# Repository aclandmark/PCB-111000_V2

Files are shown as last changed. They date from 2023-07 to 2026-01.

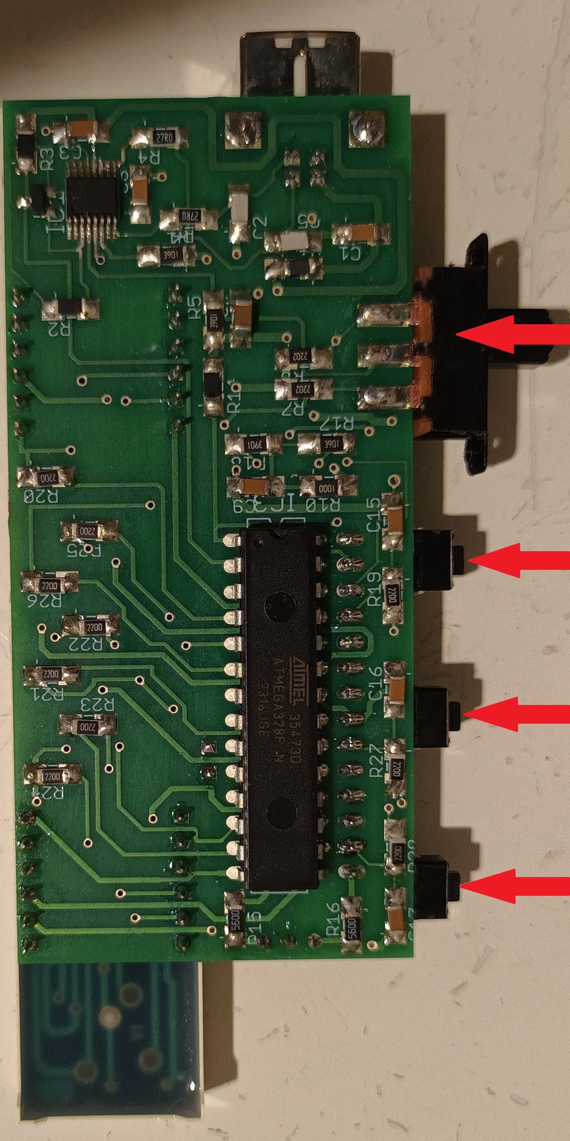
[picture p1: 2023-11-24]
Documents/PCB-111000_V2_Bottom_view.jpg

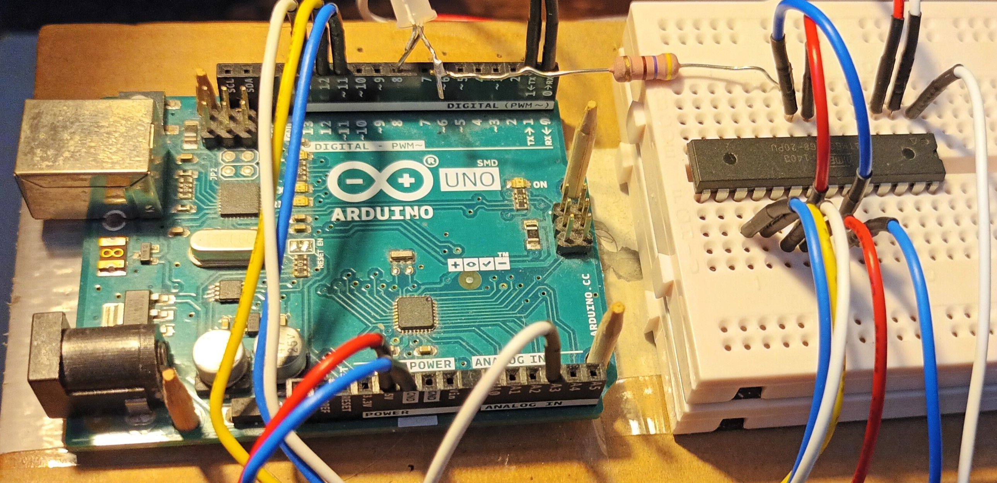
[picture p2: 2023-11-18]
Documents/UNO_programs_the_Atmega168.jpg

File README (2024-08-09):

PCB111000 has beeen developed as a learning aid for the C language when applied to AVR devices.  
It consists of a USB bridge to communicate with a PC, an 8 digit display and two AVR devices. 
One of the AVR devices (Atmega 328) hosts a programmer and miniOS which drives the display, 
the other (Atmega168), the user device, hosts user projects.

An I2C bus is used to link the two devices.
All user projects are compiled using Arduino, system projects use Arduino or Studio 7 if needed.
The boards are set up using the UNO to host a bespoke programer.  See repository "UNO_as_an_AVR_programer". 

See repository "PCB-111000/1_Documentation/1_PCB 111000 leaflet.pdf" for general information and a block diagram of the original development. 

There are three versions of PCB111000:

PCB_111000_V2 using two Atmega devices and the FTDI FT230XS USB bridge
PCB_111000_UNO_V2 A simplified plug in version for use with the UNO
PCB_111000_CP2102 Using one Atmega one ATtiny and a CP2102 module for USB connectivity.

In PCB_111000_UNO_V2 and PCB_111000_CP2102 the user device is an Atmega328 which hosts
a bootloader as well as the user projects.

In PCB_111000_CP2102 the I2C bus is replaced with a one wire firmware UART.

Originally 56 projects were developed for use with PCB111000.
These have been revised over the years and are now as follows

20 very short projects provided to show what a C program looks like and explore basic methods of program flow control
9 projects exploring the operation of the recever transmitter (USART) block
7 projects exploring interrupts
4 projects exploring bit operatons, division and the conversion between 8 bit binary and decimal numbers
11 projects based on the Arduino USART library with reset analysis including
	Interger, prime and scientific numbers
	Integer roots and a pie estimator
	Power series to compute real number powers and trig functions
	A floating point number to string sbroutine
	Displays to simulate gravity, the pendulum and a noise waveform.
9 Projects to Illustate driving the display from the keyboard and user switches, includes a simple
calculator and floating point number to 8 digit display.
7 Projects used to build simple clocks and stop watches
6 Projects used to illustrate use of Atmel Studio 7
8 projects used to illustrate the operation of floating point numbers, tested using power series as above
and the generation of pulse and sawtooth waveforms by supperimposing sine wave upon one another.
5 projects to test the operation of the PCB during assembly
5 projects used to exlore the calibration of the RC oscillators used to clock the devices.

Any bugs:	Of course there are especially in the conversion of a floating point number to 8 digits.
		Initially I tried to fix them, but stopped.  If they are of no interest to ayone else 
		then they are of no nterest to me either.

Projects for  PCB_111000_UNO_V2 and PCB_111000_CP2102:  Projects and the mini-OS for each of these pcbs 
requires updating however both include most of the initial projects.

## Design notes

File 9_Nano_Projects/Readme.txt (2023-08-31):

PCB111000_UNO and PCB111000_CP2102 projects adapted for use on original PCB111000 pcbs and compiled using Arduino Nana configured for an Atmega168 processor.

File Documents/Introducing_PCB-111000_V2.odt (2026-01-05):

PCB_111000_V2: Getting a new pcb up and running

1. Introduction

PCB_111000_V2 is a development of PCB_111000.

Both pcbs are loaded with

An Atmega 168 which hosts user projects

An Atmega 328. This hosts a mini-OS which:

Drives an 8 digit display

Hosts a pcb bootloader that programs the Atmega 168

Provides a variety of services for use by user projects

Differences are:

For the HW

The FETS used to drive the display are no longer fitted

For the SW

User projects have been revised and are now compiled using Arduino

System programs are compiled using Studio 7

PCB initialisation is carried out using the following Arduino sketches rather than bespoke HW

8_UNO_AVR_programmer_V3

5_Project_pcb_168_V2.30_Arduino_V2

2. Setting up PCB-111000_V2: Basic steps

Step 1 The PCB is loaded with all components except the displays and the Atmega devices

Step 2

Open the sketch “8_UNO_AVR_programmer_V3”. Under Tool/Board select Arduino UNO. Connect the UNO to the PC check the port number and upload the sketch.

Step 3

Close the sketch assemble the HW (see section 3) and with the aid of the Br@y++ terminal emulator use the UNO to:

Upload “5_Project_pcb_168_V2.30_Arduino_V2” to the Atmega 168

Calibrate it’s internal RC oscillator

Allow the Atmega 168 to run so that it can upload string data to its EEPROM.

Note:

Terminal emulator runs at 38.4KB and uses default settings.

See section 4 for more details.

Step 4 Load the Atmega 168 device onto the PCB111000 and test, then add the Atmega 328.

Step 5

Run “5_Project_pcb_168_V2.30_Arduino_V2” under the control of Br@y++ to setup the Atmega 328 (See section 5 for more details) by:

Uploading the mini-OS to its flash

Checking the calibration of its internal RC oscillator.

Uploading the “Hello world” strings to its EEPROM

Step 6 Overwrite “5_Project_pcb_168_V2.30_Arduino_V2” with user projects.

(See sections 6 and 7.)

Step 7 Upgrade the mini_OS if necessary (See section 8).

3. Hardware (HW) details


UNO used to program the Atmega168 before it is soldered onto the PCB111000_V2 Note: Atmega328 pin numbers given for a DIP28 device Upload “8_UNO_AVR_programmer_V3” sketch before placing the Atmega168 | UNO | | | Plug-in pcb
| UNO Pin | Atmega 328 | | Atmega168
| | Pin | Function | Pin
| 0 (Rx) | 2 | RXD | 2
| 1 (Tx) | 3 | TXD | 3
| 11 | 17 | MOSI | 17
| 12 | 18 | MISO | 18
| 13 | 19 | SCK | 19
| A3 | 26 | PC3 | 1 (Reset)
| GND | | | 8, 22
| 5V | | | 7,20
| 8 | 14 | PB0 | LED driver

4. Driving “8_UNO_AVR_programmer_V3”

Having uploaded the sketch to a UNO open Br@y++ and set it up as follows:

8 data bits, 1 stop bit, no parity or handshaking and a baud rate of 38.4KB

Click on “scan” to identify the comm port and then click on connect:

The following user prompt should be generated:

“s s s s s s s…………….”

Step 1 Click mouse pointer in the text box (at the bottom of the Br@y++ window) and

press -s- to get

“Atmega 168 detected.

Press -p- to program flash, -r- to run target, -d- to clear the target EEPROM or -x- to escape.”

Step 2 Press -p- and send “5_Project_pcb_168_V2.30_Arduino_V2.ino.eightanaloginputs”

Step 3 Follow instructions to Cal device then get user prompt “P/S P/S P/S………….”

Step 4 Press -s-, change bit rate when asked and send Text_files\on-chip_strings.txt

A bug Sometimes random text following programming. Power cycle and reprogram.

Optional steps

At P/S prompt press -v- to get program name plus version “Project_pcb_168_V2.30_Arduino”

Reset UNO and change the BR to 38.4kB to restore user prompt “s s s s s s s…………….”

Press -s- then -d- to clear “on-chip_strings” and cal bytes from Atmega168 EEPROM

Reset UNO to restore user prompt “s s s s s s s…………….”

Press -s- then -t- to recalibrate the Atmega 328 and restore user prompt “P/S P/S…...…”

Reset UNO to restore user prompt “s s s s s s s…………….”

Press -s- then -r- to restore user prompt “P/S P/S P/S………….”

Press -s- and reprogram the on-chip strings

Reset UNO to restore user prompt “s s s s s s s…………….”

Press -s- then -x- to escape

Reprogram the Atmega168 and note that it now offers a recalibration

5 Driving “5_Project_pcb_168_V2.30_Arduino_V2”

5.1 Add the Atmega 168

Solder the Atmega 168 to the PCB-111000_V2.

Press the DPDT switch left

Connect the pcb to a PC running Br@y++ running at 57.6KB.

Check the port and the user prompt “P/S P/S P/S…………..” should be generated.

Press -p- and the response TTND (Target not detected) should also be generated.

This confirms that the USB port is working correctly.

5.2 Add the Atmega 328

Solder on the Atmega 328 and press -p- again to generate the prompt:

“ATMEGA 328 detected

Press -P- to send a program file -E- to send a text file (or X to escape).

p/e p/e p/e p/e p/e p/e…..”

5.3 Upload the mini-OS to the Atmega 328

Press -p- and send

Mini-OS_V2\Hex_files\CC_files\Mini-OS_V26_CC.hex

When the LED stops flashing send 2_pcb_Bootloader_V4_28_CC.hex

Note: This assumes that Common Cathode displays are to be used. Similar files are present for Common Anode displays.

5.4 Auto cal the Atmega 328

Follow instructions to auto cal the Atmega238 and restore the “P/S……” prompt.

5.5 Upload the “Hello_world” file to the Atmega 328 EEPROM

Press -p- then -e- then -w- and send “Text_files\Hello_world.txt several times as requested.

Finally press any key to read back the file from EEPROM.

6. Run simple User Project

Press the DPDT switch right to get the “p/r p/r p/r …...” (May need to press the pcb reset switch.)

Press -p- and send

“9_Nano_Projects\System_programs\Proj_9F_Test_Proj_1\ Proj_9F_Test_Proj_1.ino.eightanaloginputs”

At the “p/r p/r p/r …...” prompt press -r- and operate the DPDT switch.

A column of numbers will be printed out.

Press sw1 to repeat.

Operate the DPDT switch and press the reset switch to restore the “p/r p/r p/r …...” prompt.

This confirms that the Atmega328 is being programmed properly and the displays can be added.

7. Check the displays

Displays are driven using a multiplexer which can make fault finding difficult.

Repeat as for section 6 but send “Proj_9G_Test_PCB_Assembly.ino.eightanaloginputs”. This turns off the multiplexer and illuminates digits one at a time.

Check for dry joints or solder bridges if any segments fail to work. This test was particularly relevant for version 1 when FETs were used to drive the display. In their absence in version 2 tracking is much simpler and solder bridges/dry joints are much less prevalent.

8. To upgrade the mini_OS

Push the DPDT switch right and press the reset switch.

Press -p- at the “p/r p/r p/r p/r p/r….” user prompt

and send 5_Project_pcb_168_V2.30_Arduino_V2.ino.eightanaloginputs

Run the project to get the “P/S P/S P/S………….”

Press S and reload file “on-chip_strings.txt” containing programmer strings

Press P then upload the new mini-OS as described in section 5.3

Note: Remember to delete line :00000001FF from end of new mini-OS file

9. Optional system files

Mini-OS_Resources\Eeprom_subroutines_PRN_alt.c:

In early designs PRN generator write to the EEPROM was too frequent and EEPROM burnout occurred. In this file the PRN uses a different location. It should be used if the

Message from the OS is always the same.

Bootloader_resources\Bootloader_main_with_OS_reset.c

This enables user projects to reset the mini-OS which is necessary if the I2C bus crashes which it does with some routines, especially I2C_Tx_2_integers().

This optional file has only been adopted for use with some boards because of the time needed for testing. See section 14 for more details.

10 Default User Project

At the p/r p/r prompt press -x- in place of -r-. This will give a series of options depending upon the project. These include a simple default project to check that the displays are being driven correctly, a print out from the “Hello World” file and details about the soft ware including the version. Note: This facility is not included with all projects but can easily be added.

11 SW downloads

There are two essential software applications that must be downloaded onto this PC. They are:

The Arduino development environment. Go to https://www.arduino.cc/en/software and download it from the Microsoft store.

Bray++ version 20130820 which can be downloaded from https://www.sites.google.com/site/terminalbpp/

Almost as important are

The portable version of Programmers notepad which can be downloaded from

http://www.pnotepad.org/download/.

An excellent text written by Joe Pardue that can be downloaded from

https://epdf.pub/c-programming-for-microcontrollers.html

The Atmega data sheet that can be downloaded from

https://www.docdroid.net/Q6jfzd3/atmega48a-pa-88a-pa-168a-pa-328-p-ds-ds40002061a-pdf

12 Getting the PCB manufacturing files

The Eagle pcb design software is required

Place the Eagle circuit design and layout drawings in a convenient folder

Open the Eagle pcb application. This takes the user to the Eagle control panel.

Click on (expand)

CAM Jobs

Examples and open example_2_layer.cam

Find and click on the Select Board button (Bottom left of the window)

Navigate to the layout drawing and select it

Its name will be confirmed at the bottom of the window

Click on

Process Job

Open folder (Eagle names this CAMOutputs)

Only the DrillFiles and GerberFiles are required for pcb fabrication

Use windows to send them to a compressed (zipped) folder.

This can be E-mailed to a pcb manufacturer.

13. PCB assembly

Eagle circuit design and layout drawings can be found under

PCB-111000_V2\PCB 111000_Eagle_drawings together with a parts list.

The Eagle pcb design software is required to view these

Photographs of the pcb are shown below.

Note the locations of the following components

The user switches sw1, sw2 and sw3

The double pole double throw switch (DPDT)

The reset switch

The Atmega 168 which is in the top side of the pcb (note also the location of pin 1)

The Atmega 328 which is in the under side of the pcb (note also the location of pin 1)

Because of the way the two Atmega devices are assembled the pins of one of them must be soldered from the device side of the board.

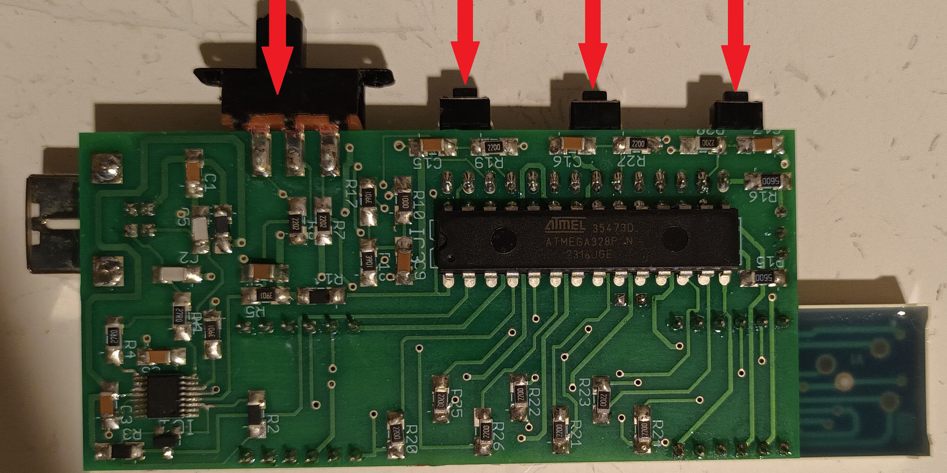
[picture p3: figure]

Note also the orientation of the two display modules.

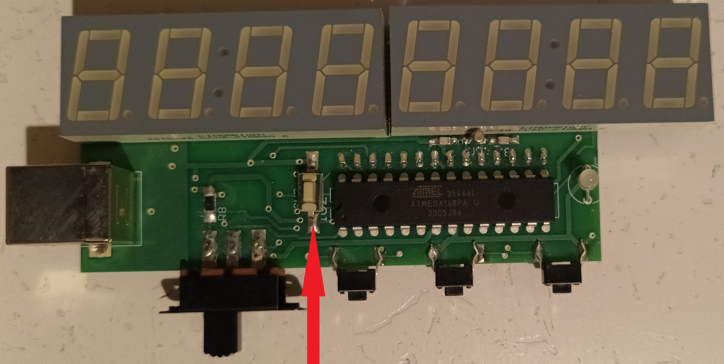
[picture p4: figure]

DPDT switch sw1 sw2 sw3 | Photo of PCB-111000V2 under side. Solder the Atmega328 to this side carefully noting its placement and the location of pin 1.
| Photo of PCB-111000V2 top side. Solder the Atmega168 to this side carefully noting its placement and the location of pin 1. Note also the orientation of the display modules
Reset switch

14 System Block diagram

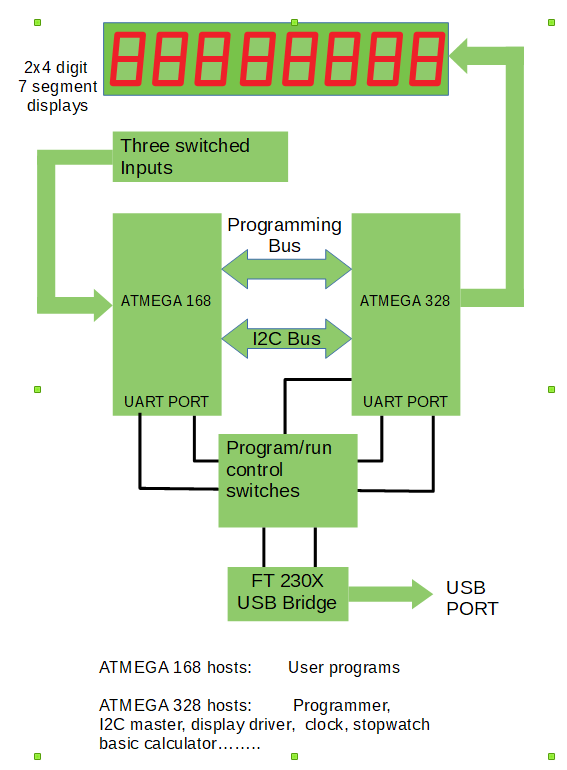
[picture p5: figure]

15 I2C bus crash

Projects designed to create patterns on the display are liable to crash if left running indefinitely or even after say 5 minutes.

A major cause of this is the I2C bus: slave and master somehow get out of step with the result that the slave finds itself waiting for a signal from the master that has already gone or for some reason never comes. The watch dog timer with interrupt is used to detect this situation. The interrupt service routine puts a reset pulse on the mini-OS IC. This alone Causes program control to jump to the programmer (location 0x7000). Therefore immediately before the reset pulse a low is put on one of the programming bus lines (PB4). The programmer detects this and sends program control to location 0x0000 (i.e. the mini-OS).

The user project “waiting_for_I2C_master” macro must be modified as follows:

activate interrupts to enable a jump to the watch dog ISR

Ensure that a time out is generated after a short (but unknown) wait as follows:

Replace the line

while (!(TWCR & (1 << TWINT)));

or

while (!(TWCR & (1 << TWINT)))wdr();

with the lines

{int m = 0; while((!(TWCR & (1 << TWINT))) && (m++ < 5000))wdr();\

if (m >= 4999){sei(); while((!(TWCR & (1 << TWINT))));}}\

These changes have only been made in projects

5I_Noise_waveform

5J_Gravity

5J_pendulum

They may easily generate unexpected side effects in other projects.

To indicate that the special version of the programmer is being used

the “p/r p/r p/r…….. user prompt in file

Bootloader_main_with_OS_reset.c

Has been changed to “p/g p/g p/g………….”

16 Programmer Bug

If -p- is pressed at the p/r prompt the first task of the programmer is to switch the target device into programming mode after which its programming memory is reset and the user is requested to send the code. Occasionally the device fails to enter programming mode however this condition has never persisted long enough to be investigated. This may be because there is a dry joint connecting the Atmega reset pins high via the 10K resistors.

In some versions of PCB111000, programming memory has only been reset after the first character of the new code has been detected. This was not found to work reliably in PCB111000_V2 so once -p- has been selected there is no escape and programming memory must be refreshed if anything is to work even the default program.

17 Mini-OS bug

The Mini-OS was originally developed using winAVR with the compiler set for full optimisation, in other words to make the executable file as small as possible.

WinAVR has subsequently been replaced by Atmel Studio 7. For this compiler full optimisation generates an executable file that is even smaller than the one generated by WinAVR. Unfortunately the mini-OS failed to function with this level of optimisation. When optimisation was turned off normal operation of the mini-OS was restored.

It is now believed that it is the I2C bus that fails with full optimisation. Ideally this should be investigated and the fault remedied so that with full optimisation and using Studio 7 everything works correctly.

This investigation has not been carried out. Instead use of the watch dog timer has been investigated. In many ways this is the more useful approach since the watch dog has widespread applications.

Recalibrating the Atmega devices

The Atmega 328 device which hosts the min-OS is recalibrated automatically.

Power cycle with DPDT to the right.

Use PCB-1111000_V2\9_Nano_projects\System_programs\ to recalibrate the Atmega 168 the user device. Note: it has not been observed that recalibration has ever been required.

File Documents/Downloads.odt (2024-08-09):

Downloads required for the Arduino Project: Checked July 2024

The Arduino development environment.

Go to https://www.microsoft.com/en-gb/store/b/sale

Click on search and type Arduino IDE

Click again, then go to download

File : Arduino IDE Installer.exe will be downloaded.

Click on it to install Arduino IDE

Note: Arduino places two folders under Documents: Arduino and Arduinodata

My current version Arduino 1.8.19 (Windows Store 1.8.57.0)

Just downloaded Arduino 1.8.19 (Windows Store 1.8.57.0)

New version Arduino 2.3.2 expected soon.

Bray++ Terminal

Go to https://www.sites.google.com/site/terminalbpp/

Several versions are available: Only one is suitable for use here.

Due to some confusion download

Terminal20130116 Last modified 16 Jan 2013 AND

Terminal20130820 Last modified 20 Aug 2013

Don’t bother with the latest version (The auto scroll does not appear to work)

I found Terminal20130116 to be OK

Programmers notepad

Go to http://www.pnotepad.org/download/ and download the portable edition

Unzip it and click on pn.exe

Text by Joe Pardue

Go to https://epdf.pub/c-programming-for-microcontrollers.html

Click on download PDF

The Microchip data sheet

Go to https://www.docdroid.net/Q6jfzd3/atmega48a-pa-88a-pa-168a-pa-328-p-ds-ds40002061a-pdf

and download.

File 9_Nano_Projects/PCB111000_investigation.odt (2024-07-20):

Development of Github_PCB-111000

Create new folders 9_Nano_Projects

and Resources_nano_projects

Go to ATMEGA_project_work_BKP_30_Sept_2022\I2C_apps_project_V10 and

Copy the files in 2_User_projects_V1_9\Resources_V12 to Resources_nano_projects

Create a new Arduino project 1_first_project

and save it under 9_Nano_Projects

Note that folder 1_first_project is created for the project

Open 2_User_projects_V1_9\….\….\Open Proj_1A1

Copy its contents into the Arduino project

Copy Proj_1A1 hex file and

Proj_1A1_header_file

into the 1_first_project folder along side the 1_first_project project

Rename the header file First_project_header

Initial tests

Upload the hex file to a PCB111000

Check it runs immediately following an -r- keypress

Gives Version data following an -x- keypress

Close and reopen the Arduino Project so that it includes the header file

Edit the #include statement to read #include "First_project_header.h"

Compile the project using Nano board Atmega 168 processor

Using setup_HW_basic;

and setup_HW

Check the following text is printed out OK

1 for OS version

2 for system data

3 Message from the OS (x to escape)

The Default project runs correctly

OS version

OS: I2C_V20_0_CA

System data:

SW information: Operating system I2C_V20_0_CA Projects V1_9 and Bootloader V4_21_CA. External programmer V2_30B

Actual operating system is Github_PCB-111000_V2\Mini-OS_V22

Update mini-OS

Github_PCB-111000 contains mini-OS version12 and 13.

Replace this OS with mini-OS_Version 20 copied from

ATMEGA_project_work_BKP_30_Sept_2022\I2C_apps_project_V10

Rebuilding mini-OS_V20 will require use of Atmel Studio 7.

Reprogramming the Atmega 328 with require the programs saved under

ATMEGA_project_work_BKP_30_Sept_2022\I2C_apps_project_V10

To update the mini-OS DO NOT EXPECT TO NEED TO DO THIS

At the p/r prompt put “4_Project_pcb_168_V2.30B” on the Atmega 168

At the ‘P’ prompt press

‘P’ to reprogram the mini-OS

‘E’ to update the “Hello world” file.

Note: Other programmers that should no longer be needed.

Version A: Same as Version B but B has one extra line to trigger auto cal of the 328.

4a_Project_pcb_328_V2.31A runs on an Atmega328

Programmer_pcb_328_V1.10 runs on a 328 and is used to put V2.30B on a 168 or replicate itself on another 328

6_BL_programmer_V1_5 was a development tool and is no longer required

If more boards are to be built a UNO will be used to put V2.30B onto an Atmega 168 and also calibrate it.

The Atmega 328 programmer applies the following config bytes to the 168

FF D5 C2 EB

V1.10 applies FF D7 E2 EB

Differences effect the brown out level and start up time.

New locations for user cal bytes Check carefully that these are always used

0x1FF User calibration byte

0x1FE User calibration byte

0x1FD Default calibration byte

0x1FC PRN generator random number HB

0x1FB PRN generator random number LB

Note: Only two locations are used here but write to EEPROM every 45 secs

2_User_projects_V1_9\Proj_9_System_projects\Proj_9A_168_manual_cal()

writes EEPROM location 0x1FA to zero.

No reason for this has been found and the line should be commented out

Problems

1 Note old problem with redefinition of

volatile char PCMSK0_mem, PCMSK2_mem;

in File I2C_subroutines_2

void I2C_Tx_float_display_control(void)

and #include "../Header_files/I_O_from switches.h"

Solution copied from PCB111000_UNO Compiles OK but not fully tested.

2 I2C_subroutines_2 line 121 SOLVED

Commented out for time being.

Calibration programs All OK

Copy the following two calibration routines to

9_Nano_Projects\System_programs

2_User_projects_V1_9\Proj_9A_168_manual_cal

and \Proj_9B_168_auto_cal

Compile with Arduino_nano_168 and calibrate two pcbs successfully.

Note Problem 2 above

Note: The Atmega 328 (mini-OS device calibrates itself automatically at every POR)

provided the DPDT is switched to the right.

1_first_project 12 examples

Example 1 Ramp with SW reset Tested OK

Example 1A Ramp with WDT generated reset Tested OK

Example 2 Back and forth with WDT Tested OK

Example 3 Chase (spurious wdr(); removed) Tested OK

Example 4 Single ellipse (spurious wdr(); removed) Tested OK

Example 5 Double ellipse (spurious wdr(); removed) Tested OK

Example 6 Upper/lower see saws Tested OK

Example 7 Moving top Tested OK

Example 7A Moving top (with reset on sw3) Tested OK

Example 8 Leds leapfrog WDT added Tested OK

Example 9 LEDS light up in random order (with reset) Tested OK

Example 10 Default program with WDT Tested OK

Tested with setup_HW_extra

Example_1 Modes 0 – 4 tested OK Saved as Example_1E

Example_4 Modes 0 – 4 tested OK Saved as Example_4E

Example_7 Modes 0 – 4 tested OK Saved as Example_7E

Example_9 Modes 0 – 4 tested OK Saved as Example_9E

2_Receiver_Transmitter_Basic

Example_1 Tested OK

Example_2 Tested OK

Example_3 Tested OK

Example_4 Reset implemented Tested OK

Example_5 Reset implemented Tested OK

Example_6 Reset implemented Tested OK

Example_7 Tested OK

Example_8 Tested OK

Example_9 Tested OK

Tested with setup_HW_extra

Example_1

Example_3

Example_5

Example_7

3_Interrupts_and_switches

Basic HW HW_Extra

3A_UART_timer_interrupts OK OK

3B_Pin_Change_Interrupt OK OK

3C_reaction_time_tester OK OK

3D_timer_PCI_interrupts OK OK

3E_Keypress_logger OK OK

3F_Prime_numbers OK OK

3G_Prime_numbers_plus OK OK

4_binary_and_bit_operations

1_Bit_ops_1 OK OK

2_Bit_ops_2 OK OK

3_Division_subroutine OK OK

4_Char_to_binary OK OK

5_Timers Performance degraded by tendency of I2C bus to crash.

Resolved using watch dog with interrupt

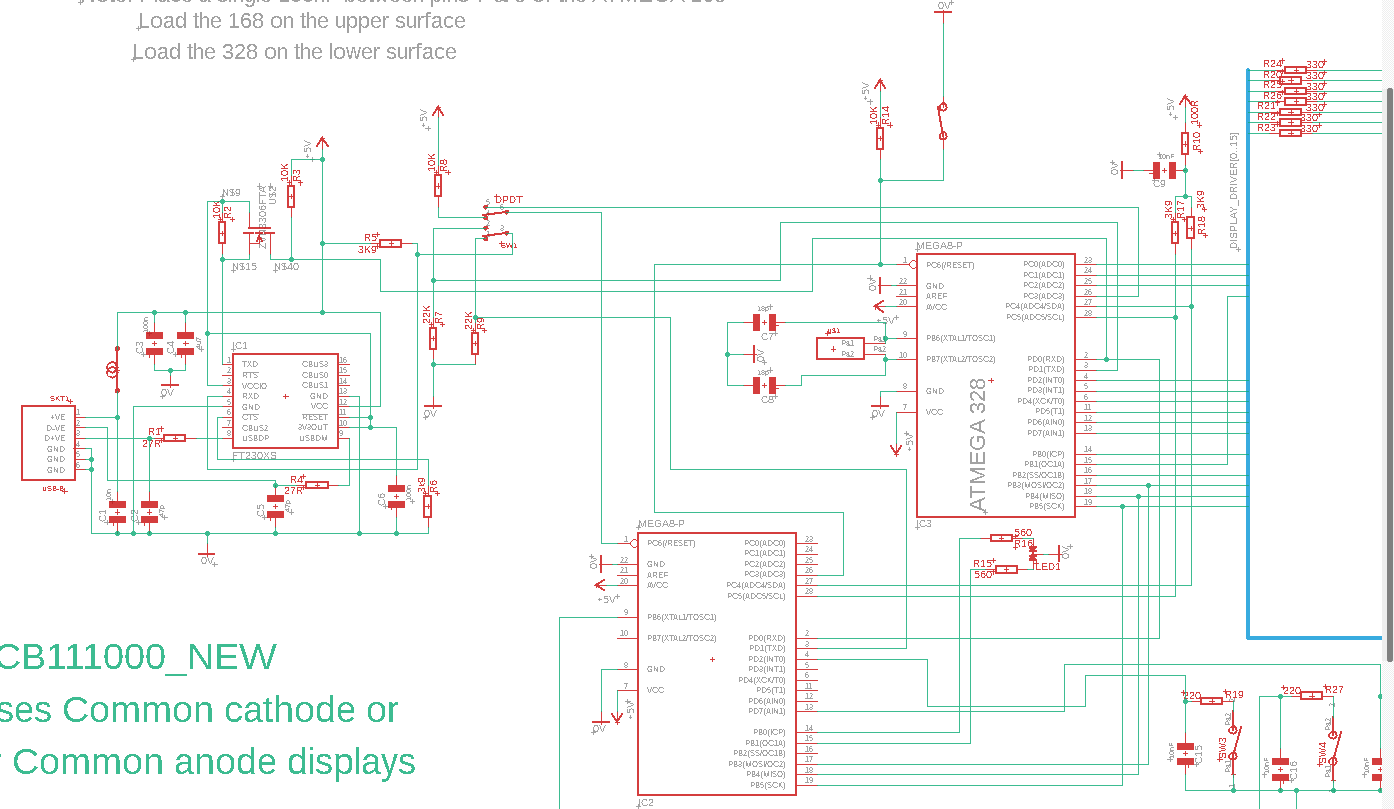
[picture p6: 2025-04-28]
PCB 111000_Eagle_drawings/Version 2 design/Schematic.bmp

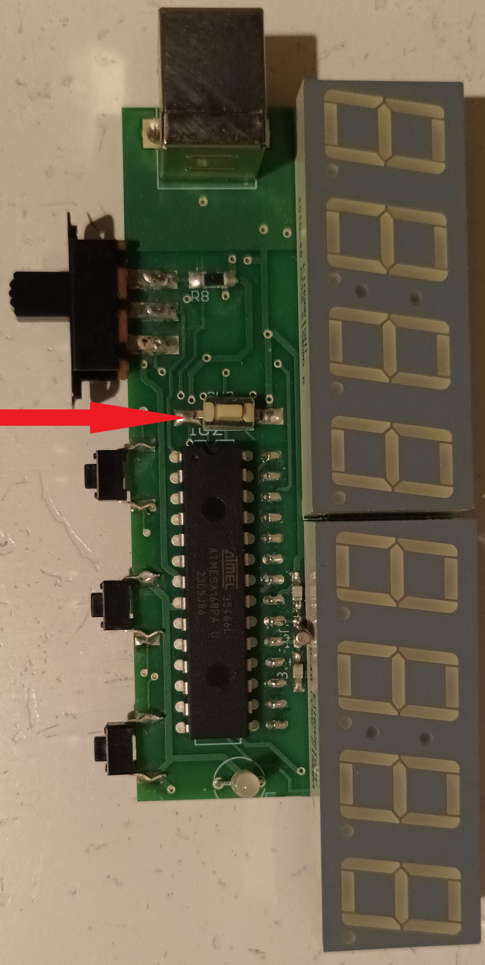
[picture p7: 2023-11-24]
Documents/PCB-111000_V2_Top_view.jpg

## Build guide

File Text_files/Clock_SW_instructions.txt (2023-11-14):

"Having entered the time it is also possible to reconnct the pcb to a 5V supply.Then press sw3/sw1 to start the clock. 
Toggle sw1 to switch between the clock and a new SW or press sw2 to select old SW.
Press sw3 to pause, blank or resume the display.
To adjust the time: Press sw1 to restore clock time then immediately press sw3.
Release sw3 to increment time or sw1 to decrement it then both switches to restore normal operation.
Press sw3 or 2 then sw1 to continue."

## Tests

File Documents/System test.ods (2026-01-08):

 | VERSION 3 | Check with new | EEPROM | Locations | 0x1F | becomes | 0x3F
 |  |  |  | Del old code from |  | .hex file changes from |  |  | Load 5A |  |  |  |  |  | Load
 |  |  |  | Pcb bootloader | mini-OS | Pcb bootloader | mini-OS |  | Runs | OS version | Sys data | Hello World | Default Prog | Runs | 9B | 9A | 9C | 9D | 9E | Intensity_tests | Mux demo | 6D | 9D | 9F | 1_9 | 7C
V1 CA (V4_29 & V27) |  |  | Updated | Done | Done | OK | OK | Updated | OK | OK | OK | OK | OK | OK | 68 | 8C | 9B | OK | OK | OK | OK | OK | OK | OK | OK | OK
V1 CC (V4_30 & V28) |  |  | Updated | Done | Done | OK | OK | Updated | OK | OK | OK | OK | OK | OK | 56 | 56 | A4 |  |  | OK | OK | OK | OK | OK | OK
V1 CC (V4_30 & V28) | alt_PRN |  | Updated | Done | Done | OK | OK | Updated | OK | OK | OK | OK | OK | OK | 51 | 51 | AC | OK | OK | OK | OK | OK | OK | OK | OK | OK
V1 CA (V4_29 & V27) | ****** | COM4 |  |  |  |  |  |  | OK |  |  | OK | OK | OK | 74 | B6 (B5) | B3 (AD) |  |  | OK | OK |  | OK | OK | OK | OK
V2 CA (V4_31 & V29 ) |  |  | Updated | Done | Done | OK | OK | Updated | OK | OK | OK | OK | OK | OK | 6F | B2 | 8C | OK | OK | OK | Ok |  | OK | OK |  | OK
V2 CA (V4_31 & V29 ) |  |  | Updated | Done | Done | OK | OK | Updated | OK | OK | OK | OK | OK | OK | 6F | B1 | B7 | OK | OK | OK | OK |  | OK | OK |  | OK
V2_CC(V4_32 & V30) | repaired |  | Updated | Done | Done | OK | OK | Updated | OK | OK | OK | OK | OK | OK | 5C | 98 | A8 | A8,64 | OK | OK | OK | OK | OK | OK | OK | OK
V2_CC(V4_32 & V30) |  | Comm 12 |  |  |  |  |  |  | OK | OK | OK | OK | OK | OK | 45 | 45 | A2 | OK | OK | OK | OK |  | OK | OK | OK
****** | Version with plug in device and wiring: Display not quite uniform on low and moderate intensity |  | Version with plug in device and wiring: Display not quite uniform on low and moderate intensity | Version with plug in device and wiring: Display not quite uniform on low and moderate intensity | Version with plug in device and wiring: Display not quite uniform on low and moderate intensity | 8 bit PRN uses 0x3F6 |  | Intermittent programming bus
 |  | Intensity | MUX | Intensity | Cal 9B | Cal 9A | Cal 9C | 5A OS | 5A sys | 5A hello world | 5A Default | 8D | 9D | 9F | 1_5
V1_CA Com 6 |  | OK | OK | OK | 62 | 8D (93) | B2 (B2) | OK | OK | OK | OK | OK | OK | OK | OK
V1_CA Com 25 |  | OK | OK | OK | 5E | 89 (91) | AE (AD) | OK | OK | OK | OK | 8D | 9D | OK | OK
V1_CA Com 24 |  | OK | OK | OK | 5D | 89 (90) | AF (B0) | OK | OK | OK | OK | OK | OK | OK | OK
V1_CA Com 7 |  | OK | OK | OK | 54 | 54 (5D) | BA (BA) | OK | OK | OK | OK | OK | OK | OK | OK
V1_CA Com 8 |  | OK | OK | OK | 59 (84) | 81 | 99 (9E) | OK | OK | OK | OK | OK | OK | OK | OK
V1_CA Com 12 |  | OK | OK | OK | 70 | A0 (A2) | AB (AE) | OK | OK | OK | OK | OK | OK | OK | OK
V1_CA Com 17 | Faulty Reset | OK | OK | OK | 5C (80) | 5C | 88 (85) | OK | OK | OK | PK | OK | OK | OK
 | Switch FIXED
V1_CA Com 9 | Intermittent | OK | OK | OK | 42 | 45 (4E) | AC (AD) | OK | OK | OK | OK | OK | OK | OK | OK
 | programming bus
V1_CA Com 23 | Intermittent | OK | OK | OK | 6F | A4 (A6) | 39 (42) | OK | OK | OK | OK | OK | OK | OK | OK
 | programming bus
V1_CA Com 35 |  | OK | OK | OK | 81 | 5C (85) | 8F (92) | OK | OK | OK | OK | OK | OK | OK | OK
V1_CC Com 20 |  | OK | OK | OK | 67 | 8F (92) | 98 (9B) | OK | OK | OK | OK
V1_CC Com 15 |  | OK | OK | OK | 58 | 58 (5C) | C4 (C2) | OK | OK | OK | OK
V1_CC Com 14 |  | OK | OK | OK | 4F | 50 (56) | A7 (AB) | OK | OK | OK | OK
V1_CC Com 21 |  | OK | OK | OK | 4E | 4E (55) | AE (AF) | OK | OK | OK | OK
V1_CC Com 22 |  | OK | OK | OK | 52 | 52 (59) | B5 (B6) | OK | OK | OK | OK
V1_CC Com 26 |  | OK | OK | OK | 57 | 59 (5C) | B5 (B7) | OK | OK | OK | OK
V1_CC Com 27 |  | OK | OK | OK | 5B | 5B (5D) | A8 (A8) | OK | OK | OK | OK
V1_CC Com 34 CC10 | Intermittent | OK | OK | OK | 5E | 83 (8E) | 94 (96) | OK | OK | OK | OK
 | programming bus
V1_CC Com 19 |  | OK | OK | OK | 5A | 5A (80) | 93 (98) | OK | OK | OK | OK

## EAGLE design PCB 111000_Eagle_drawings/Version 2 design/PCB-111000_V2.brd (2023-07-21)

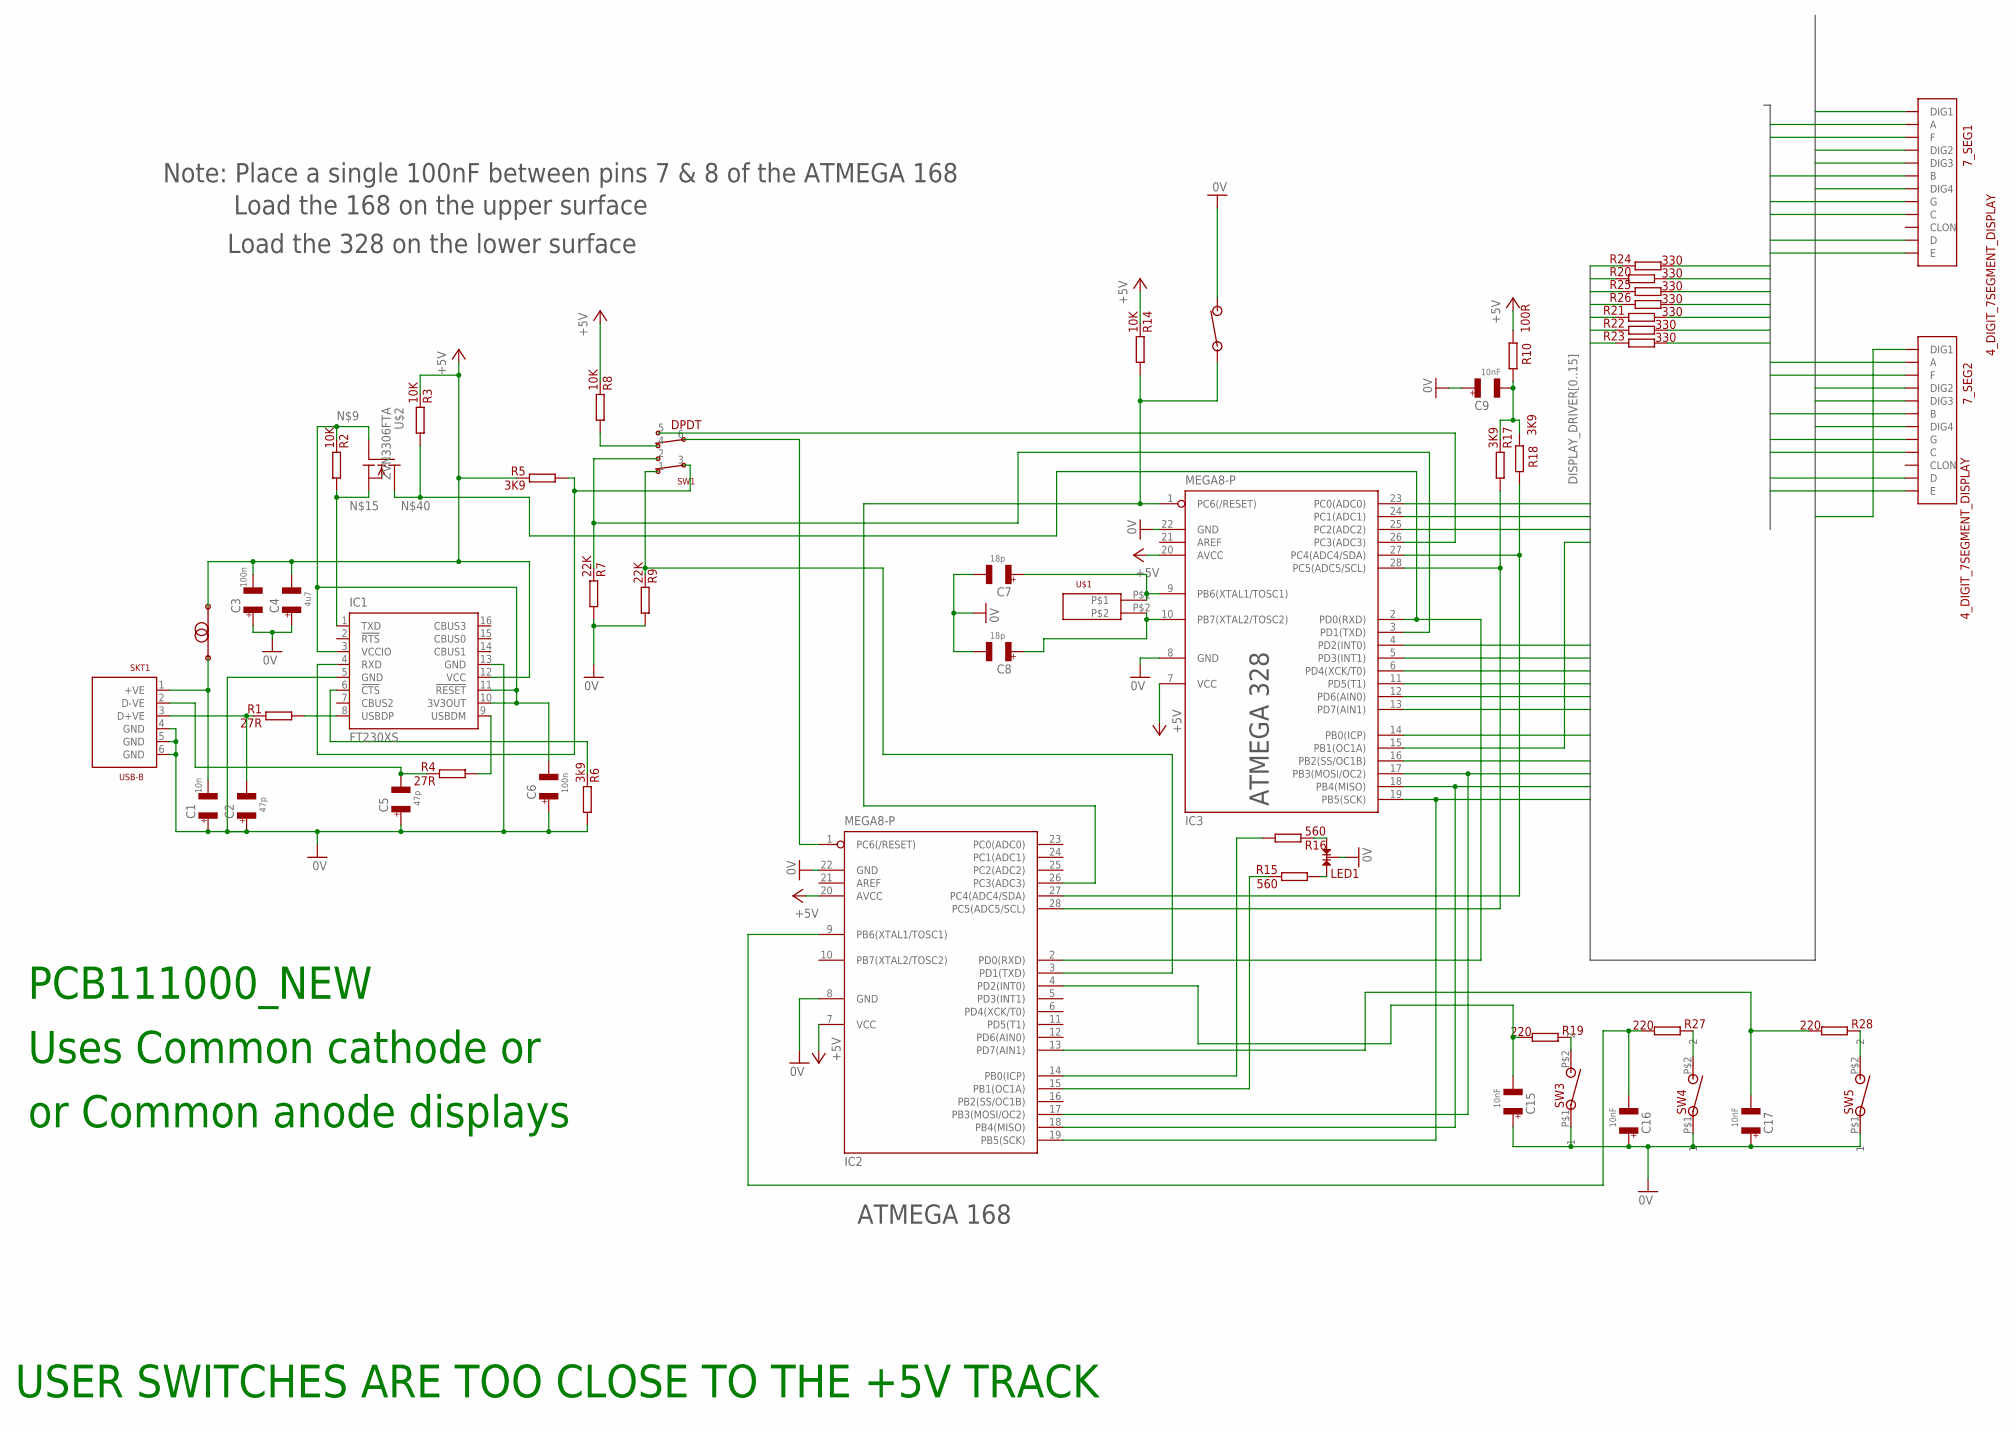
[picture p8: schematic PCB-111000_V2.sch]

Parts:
7_SEG1, 7_SEG2: 4_DIGIT_7SEGMENT_DISPLAY
C1: 10n; 1206
C2, C5: 47p; 1206
C3, C6: 100n; 1206
C4: 4u7; 1206
C7, C8: 18p; 0805
C9, C15, C16, C17: 10nF; 1206
IC1: FT230XS; SSOP16
IC2, IC3: MEGA8-P; DIL28-3
L1: CHOKE; 1206
LED1: LED; CA_DUAL_LED
R1, R4: 27R; 1206
R2, R3, R8, R14: 10K; 1206
R5, R17, R18: 3K9; 1206
R6: 3k9; 1206
R7, R9: 22K; 1206
R10: 100R; 1206
R15, R16: 560; 1206
R19, R27, R28: 220; 1206
R20, R21, R22, R23, R24, R25, R26: 330; 1206
SKT1: USB-B
SW1: DPDT; DPDT_SWITCH
SW2: NO_SW; SM_NO_PUSH_BUTTON
SW3, SW4, SW5: NO_PB_1; RE51-0711
U$1: XTAL; XTAL_VIAS
U$2: ZVN3306FTA; SOT-23

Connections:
0V: C1.P$1 (1), C2.P$1 (1), C3.P$1 (1), C4.P$1 (1), C5.P$1 (1), C6.P$1 (1), C7.2, C8.2, C9.P$1 (1), C15.P$1 (1), C16.P$1 (1), C17.P$1 (1), IC1.5 (GND), IC1.13 (GND), IC2.8 (GND), IC2.22 (GND), IC3.8 (GND), IC3.22 (GND), LED1.2, R6.P$1, R7.P$1, R9.P$1, SKT1.4 (GND), SKT1.5 (GND), SKT1.6 (GND), SW2.P$2 (2), SW3.P$1 (1), SW4.P$1 (1), SW5.P$1 (1)
+5V: C3.P$2 (2), C4.P$2 (2), IC1.12 (VCC), IC2.7 (VCC), IC2.20 (AVCC), IC3.7 (VCC), IC3.20 (AVCC), L1.P$2 (2), R3.P$2, R5.P$2, R8.P$2, R10.P$2, R14.P$2
DISPLAY_DRIVER0: IC3.15 (PB1(OC1A)), R24.P$2
DISPLAY_DRIVER1: IC3.4 (PD2(INT0)), R20.P$2
DISPLAY_DRIVER2: IC3.5 (PD3(INT1)), R25.P$2
DISPLAY_DRIVER3: IC3.6 (PD4(XCK/T0)), R26.P$2
DISPLAY_DRIVER4: IC3.11 (PD5(T1)), R21.P$2
DISPLAY_DRIVER5: IC3.12 (PD6(AIN0)), R22.P$2
DISPLAY_DRIVER6: IC3.13 (PD7(AIN1)), R23.P$2
DISPLAY_DRIVER8: 7_SEG2.P$12 (DIG1), IC3.14 (PB0(ICP))
DISPLAY_DRIVER9: 7_SEG2.P$9 (DIG2), IC3.16 (PB2(SS/OC1B))
DISPLAY_DRIVER10: 7_SEG2.P$8 (DIG3), IC2.17 (PB3(MOSI/OC2)), IC3.17 (PB3(MOSI/OC2))
DISPLAY_DRIVER11: 7_SEG2.P$6 (DIG4), IC2.18 (PB4(MISO)), IC3.18 (PB4(MISO))
DISPLAY_DRIVER12: 7_SEG1.P$12 (DIG1), IC2.19 (PB5(SCK)), IC3.19 (PB5(SCK))
DISPLAY_DRIVER13: 7_SEG1.P$9 (DIG2), IC3.23 (PC0(ADC0))
DISPLAY_DRIVER14: 7_SEG1.P$8 (DIG3), IC3.24 (PC1(ADC1))
DISPLAY_DRIVER15: 7_SEG1.P$6 (DIG4), IC3.25 (PC2(ADC2))
unnamed: IC2.14 (PB0(ICP)), R16.P$1
unnamed: IC2.15 (PB1(OC1A)), R15.P$2
unnamed: LED1.1, R15.P$1
unnamed: LED1.3, R16.P$2
unnamed: IC3.26 (PC3(ADC3)), SW1.5
unnamed: IC3.3 (PD1(TXD)), R7.P$2, SW1.2
unnamed: R27.P$2, SW4.P$2 (2)
unnamed: R19.P$2, SW3.P$2 (2)
unnamed: C6.P$2 (2), IC1.3 (VCCIO), IC1.10 (3V3OUT), IC1.11 (!RESET), R2.P$2, U$2.3 (G)
unnamed: C7.1, IC3.9 (PB6(XTAL1/TOSC1)), U$1.P$1
unnamed: C17.P$2 (2), IC2.13 (PD7(AIN1)), R28.P$1
unnamed: C8.1, IC3.10 (PB7(XTAL2/TOSC2)), U$1.P$2
unnamed: R8.P$1, SW1.4
unnamed: IC2.3 (PD1(TXD)), R9.P$2, SW1.1
unnamed: IC1.1 (TXD), R2.P$1, U$2.2 (S)
unnamed: R28.P$2, SW5.P$2 (2)
unnamed: C15.P$2 (2), IC2.4 (PD2(INT0)), R19.P$1
unnamed: IC1.9 (USBDM), R4.P$1
unnamed: C16.P$2 (2), IC2.9 (PB6(XTAL1/TOSC1)), R27.P$1
unnamed: C9.P$2 (2), R10.P$1, R17.P$2, R18.P$2
unnamed: IC1.8 (USBDP), R1.P$1
unnamed: IC2.1 (PC6(/RESET)), SW1.6
unnamed: C5.P$2 (2), R4.P$2, SKT1.2 (D-VE)
unnamed: C2.P$2 (2), R1.P$2, SKT1.3 (D+VE)
unnamed: C1.P$2 (2), L1.P$1 (1), SKT1.1 (+VE)
unnamed: IC2.26 (PC3(ADC3)), IC3.1 (PC6(/RESET)), R14.P$1, SW2.P$1 (1)
unnamed: IC1.6 (!CTS), R6.P$2
unnamed: IC1.4 (RXD), R5.P$1, SW1.3
unnamed: IC2.28 (PC5(ADC5/SCL)), IC3.28 (PC5(ADC5/SCL)), R17.P$1
unnamed: IC2.27 (PC4(ADC4/SDA)), IC3.27 (PC4(ADC4/SDA)), R18.P$1
unnamed: IC2.2 (PD0(RXD)), IC3.2 (PD0(RXD)), R3.P$1, U$2.1 (D)
SEVEN_SEG0: 7_SEG1.P$11 (A), 7_SEG2.P$11 (A), R24.P$1
SEVEN_SEG1: 7_SEG1.P$7 (B), 7_SEG2.P$7 (B), R20.P$1
SEVEN_SEG2: 7_SEG1.P$4 (C), 7_SEG2.P$4 (C), R25.P$1
SEVEN_SEG3: 7_SEG1.P$2 (D), 7_SEG2.P$2 (D), R26.P$1
SEVEN_SEG4: 7_SEG1.P$1 (E), 7_SEG2.P$1 (E), R21.P$1
SEVEN_SEG5: 7_SEG1.P$10 (F), 7_SEG2.P$10 (F), R22.P$1
SEVEN_SEG6: 7_SEG1.P$5 (G), 7_SEG2.P$5 (G), R23.P$1

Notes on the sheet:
Note: Place a single 100nF between pins 7 & 8 of the ATMEGA 168
ATMEGA 168
ATMEGA 328
Load the 168 on the upper surface
Load the 328 on the lower surface
or Common anode displays
PCB111000_NEW
Uses Common cathode or
USER SWITCHES ARE TOO CLOSE TO THE +5V TRACK

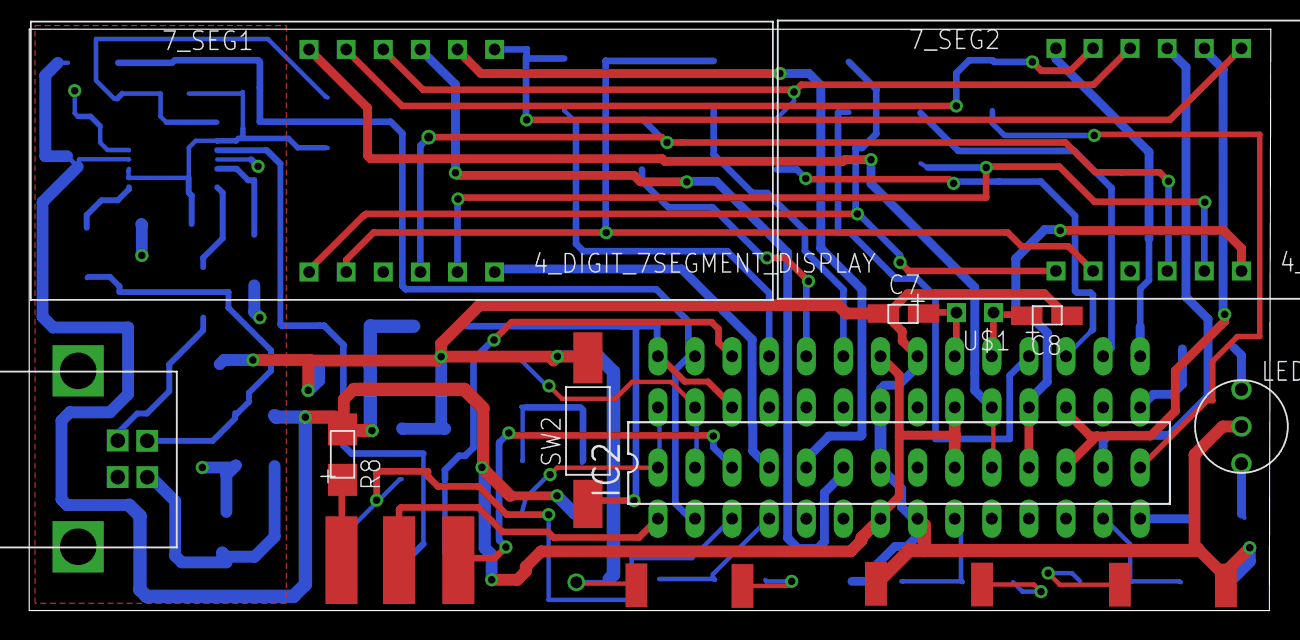
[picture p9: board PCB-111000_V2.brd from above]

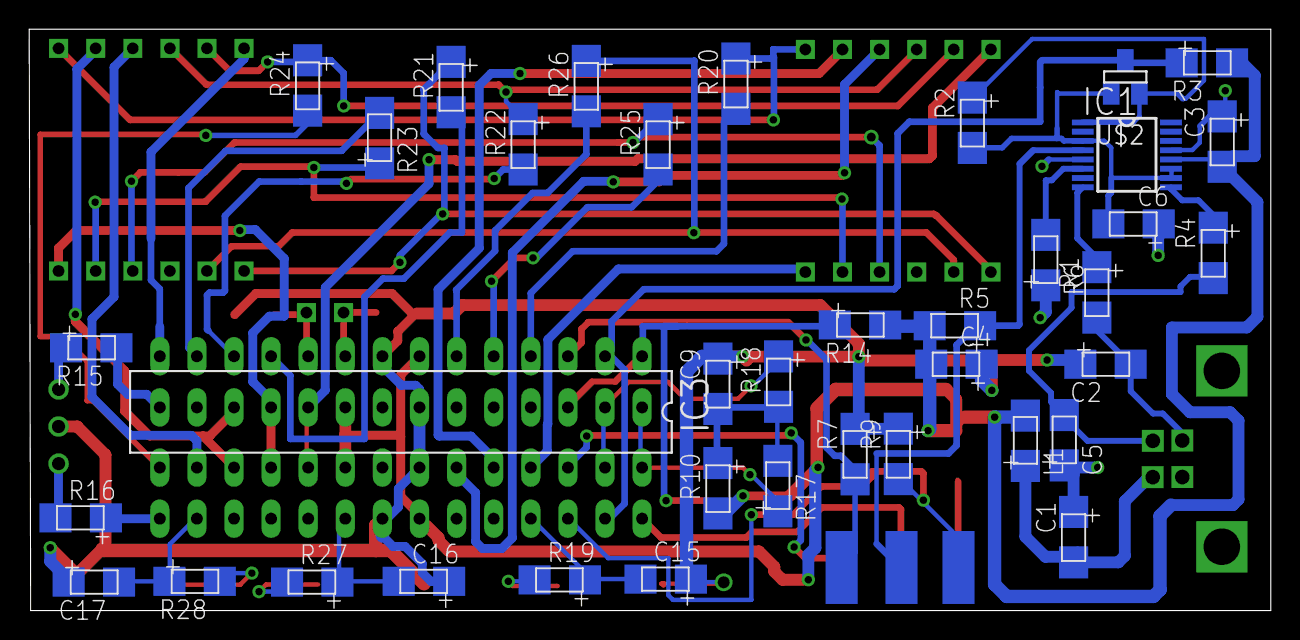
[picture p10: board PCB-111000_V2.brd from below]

Board: 2 copper layers, 85.0 x 39.8 mm, 52 parts (39 on the bottom side), 55 nets.

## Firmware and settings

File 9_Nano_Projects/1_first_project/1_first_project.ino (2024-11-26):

/*
EEPROM usage
0x1FF, 0x1FE and 0x1FD		OSCCAL
0x1FC and 0x1FB				PRN generator
*/


#include "First_project_header.h"

int main (void)                          //Example 1
  { unsigned int PORT_1;

  setup_HW;
    PORT_1 = 1;
  for (int m = 0; m <= 15; m++)
  {  I2C_Tx_2_integers(PORT_1, PORT_1);
    Timer_T0_10mS_delay_x_m(12);
   PORT_1 = PORT_1 << 1;
   }
  SW_reset;
    }
  
 
/**************************************************************************************************

  Use this area for saving the examples when they have been got working and finished with
  Use the space above for the active program (the one being worked on)


***************Example 1: One bar sweep right to left*********************************************
int main (void)                          //Example 1
  { unsigned int PORT_1;

  setup_HW;
    PORT_1 = 1;
  for (int m = 0; m <= 15; m++)
  {  I2C_Tx_2_integers(PORT_1, PORT_1);
    Timer_T0_10mS_delay_x_m(12);
   PORT_1 = PORT_1 << 1;
   }
  SW_reset;
    }


  ***********************************************************************************************
int main (void)                          //Example 1A
  { unsigned int PORT_1;

  setup_HW;
  wdt_enable(WDTO_30MS);
    PORT_1 = 1;
  for (int m = 0; m <= 15; m++)
  {  I2C_Tx_2_integers(PORT_1, PORT_1);
    Timer_T0_10mS_delay_x_m(12);
   PORT_1 = PORT_1 << 1;
   }
  while(1);
    }

***************Example 2: One bar sweep right to left and back to right again*********************
int main (void)                          //Example 2
  { unsigned int PORT_1;

  setup_HW;
  wdt_enable(WDTO_30MS);
  PORT_1 = 1;
  for (int m = 0; m <= 15; m++)
  {  I2C_Tx_2_integers(PORT_1 << m, PORT_1 << m);
    Timer_T0_10mS_delay_x_m(12);
   }
for (int m = 14; m; m--)
{  I2C_Tx_2_integers(PORT_1 << m, PORT_1 << m);
    Timer_T0_10mS_delay_x_m(12);
   }
  while(1);
  }


  
  ***********************************************************************************************
#include "Local_subroutines.c"

int main (void)                          //Example 2A
  { unsigned int PORT_1;
    int T1_period = 15;

  setup_HW;
  while(1){
  PORT_1 = 1;
  for (int m = 0; m <= 15; m++)
  {  I2C_Tx_2_integers(PORT_1 << m, PORT_1 << m);
    Timer_T0_10mS_delay_x_m(T1_period);}
for (int m = 14; m; m--)
{  I2C_Tx_2_integers(PORT_1 << m, PORT_1 << m);
    Timer_T0_10mS_delay_x_m(T1_period); }
   if(switch_1_down)T1_period = Adjust_T1_period(T1_period);}}




 ***************Example 3: Both half bars running back and forth together**************************
 int main (void)                          //Example 3
  { unsigned int PORT_1, PORT_2;

  setup_HW;
  while (1)
  { PORT_1 = 0b0000000000000001;      //1
    PORT_2 = 0b1000000000000000;     //0x8000;
    for (int m = 0; m <= 15; m++)
    { I2C_Tx_2_integers(PORT_1, PORT_2);
      _delay_ms(60);
      PORT_1 = PORT_1 << 1;
      PORT_2 = PORT_2 >> 1;
    }
  }
  return 1;
  }



***************Example 4: Single half bar runs back and forth**************************************
  int main (void)                          //Example 4
  { unsigned long PORT_1, PORT_2;

  setup_HW;
  while (1)
  { PORT_1 = 1;
    PORT_2 = 0x80000000;
    for (int m = 0; m <= 31; m++)
    {  I2C_Tx_2_integers(PORT_1, PORT_2);
      _delay_ms(60);
      PORT_1 = PORT_1 << 1;
      PORT_2 = PORT_2 >> 1;
    }
  }
  return 1;
  }


*****************Example 5: Four half bars execute two ellipses************************************
 int main (void)                          //Example 5
  { unsigned int PORT_1, PORT_2;

 setup_HW;
  while (1)
  { PORT_1 = 1;
    PORT_2 = 0x8000;
    for (int m = 0; m <= 7; m++)
    { I2C_Tx_2_integers(PORT_1 | PORT_2,
      (PORT_1 << 8)  | (PORT_2 >> 8));
      _delay_ms(60);
      PORT_1 = PORT_1 << 1;
      PORT_2 = PORT_2 >> 1;
    }
  }
  return 1;
  } 






******************Example 6: Two half bars execute see-saw motion *********************************
 int main (void)                          //Example 6
  { unsigned int PORT_1, PORT_2, m = 0, n = 0;

  setup_HW;
  PORT_1 = 1;
  PORT_2 = 0x8000;
  while (1)
  { I2C_Tx_2_integers(PORT_1 << m, PORT_2 >> m);
    _delay_ms(60);
    if (!(n)) m += 1;
    if (m == 16)n = 1;
    if (n == 1)m -= 1;
    if (m == 0)n = 0;
  }
  return 1;
  }




******************Example 7: Multi bar display****************************************************
int main (void)                          //Example 7
  { unsigned int PORT_1 = 1;
  char m = 1;
  char overflow = 0;

  setup_HW;
  while (1)
  { I2C_Tx_2_integers(PORT_1, ~PORT_1);
    
    _delay_ms(80);
    
    if (m <= 5)
    {
      PORT_1 |= (PORT_1 << 1);
      m += 1;
    wdr();}
    else PORT_1 = PORT_1 << 1;
    if (overflow)PORT_1 |= 1;
    if (PORT_1 & 0x8000) overflow = 1;
    else overflow = 0;
  }
  }  

int main (void)                          //Example 7A
  { unsigned int PORT_1 = 1;
  char m = 1;
  char overflow = 0;

  setup_HW;

  wdt_enable(WDTO_30MS);
  while(switch_1_down)wdr();
  
  while (1)
  { I2C_Tx_2_integers(PORT_1, ~PORT_1);
    
    Timer_T0_10mS_delay_x_m(8);
    
    if (m <= 5)
    {
      PORT_1 |= (PORT_1 << 1);
      m += 1;
    wdr();}
    else PORT_1 = PORT_1 << 1;
    if (overflow)PORT_1 |= 1;
    if (PORT_1 & 0x8000) overflow = 1;
    else overflow = 0;
    while(switch_1_down);
  }
  }






*****************Example 8: Leds sweep left to right with random motion***************************
int main (void)                          //Example 8
  { unsigned int random_num;
  unsigned char PRN_counter;
  long PORT_1 = 1, PORT_2 = 1;

  setup_HW;
  wdt_enable(WDTO_30MS);
  PRN_counter = 0;
  random_num = PRN_16bit_GEN (0, &PRN_counter);
  while (1)
  { for (int m = 0; m < random_num % 3; m++)
    { if (!(PORT_1 = ((PORT_1 * 2) % 0x10000)))
        PORT_1 = 1;
    }
    if (!(PORT_2 = ((PORT_2 * 2) % 0x10000)))PORT_2 = 1;
    I2C_Tx_2_integers(PORT_1, PORT_2);
    Timer_T0_10mS_delay_x_m(8);
    random_num = PRN_16bit_GEN (random_num, &PRN_counter);
  }
  }  



*****************Example 9: The default program****************************************************
 
#include "Local_subroutines.c"

unsigned int PRN;
unsigned char PRN_counter;

 int main (void)                             //Example 9
  {int T1_period = 15;
  char direction;
  char seg_counter;
  setup_HW;
  
  I2C_Tx_any_segment_clear_all();
  PRN_counter = 0;
  PRN = PRN_16bit_GEN (0, &PRN_counter);
   direction=1;
  while(1){
     direction ^= 1;
   seg_counter=0;
 PRN = update_display(T1_period, direction, seg_counter, PRN);
 if(switch_1_down); else T1_period = Adjust_T1_period(T1_period);}}



*****************Example 10: Another Random number display*****************************************
int main (void)                          //Example 10
{ unsigned int PRN;
  unsigned char PRN_counter;

  setup_HW;
  wdt_enable(WDTO_30MS);
  PRN_counter = 0;
  PRN = PRN_16bit_GEN (0, &PRN_counter);
  while (1)
  { PRN = PRN_16bit_GEN (PRN, &PRN_counter);
    I2C_Tx_2_integers(PRN, (PRN << ((PRN % 2) + 1)));
    Timer_T0_10mS_delay_x_m(10);
  }
}



  
 **************************************************************************************************/

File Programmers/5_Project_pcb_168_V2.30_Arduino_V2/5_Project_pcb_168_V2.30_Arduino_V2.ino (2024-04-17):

/*****ATMEGA programmer "5_Project_pcb_168_V2.30_Arduino_V2" developed specially for the "Github_PCB-111000_V2" Project 


*******Runs on the Atmega 168
*******See also "8_UNO_AVR_Programmer_V3" which programs the Atmega 168 


********The Atmega 168 is the used to 
********program the ATMEGA 328 EEPROM with the "Hello World" text file and 
********flash with the mini-Os plus pcb-bootloader**********

Push the DPDT switch left and get the "P/S   P/S   P/S........" user prompt on the Br@y++ terminal program set to 57600Baud

  Press "V" to retrieve version details
  Press P to program the mini-OS+pcb-bootloader or EEEPROM

  Press -p- again and send the mini-OS parts 1 and 2 followed by the bootloader
  Follow instruction to calibrate the Atmega 328

  When the "P/S   P/S   P/S........" user prompt is restoted press -p- then -e-
  and send the "Hello World" text file.

  To run bootloader acquire the standard user prompt "P/S   P/S   P/S........" 
switch the DPDT to the right and press the reset switch.

The user prompt changes to "p/r   p/r   p/r   p/r........"

Press -p- and send a user project file
Press -x- to run the file and operate the DPDT switch
Press-3- to read the "Hello world" strings
Press -x- to run the project

To update the mini-OS

At the "p/r   p/r   p/r   p/r........" prompt press -p- and send "5_Project_pcb_168_V2.30_Arduino_V2"
Press -r- and operate the DPDT to get the "P/S   P/S   P/S......" prompt
Press -s- to restore the on-chip strings
Press -p- twice to update the mini-OS
Press -p- then -e- then -r- to check the EEPROM

Operate the DPDT and prress the reset switch to restore the "p/r   p/r   p/r   p/r........" prompt
*/




#include "Project_pcb_168_V2.30_Arduino.h"

#define Version "\r\nProject_pcb_168_V2.30_Arduino"




int main (void){ 
unsigned int target_type = 0, target_type_M;  
char keypress, sign;
char op_code = 0;
unsigned char fuse_H = 0;
int long cal_error;
long error_up, error_down, error_percent;

cal_factor= 0;                                                  //Set to 1 by OSC_CAL if user cal is available
setup_HW;



/*************************************UNO calibrates Atmega168 if necessary*******************************************/

if(!(eeprom_read_byte((uint8_t*)(0x1FC))))                      //Cleared by 8_UNO_AVR_Programmer_V3 
{Auto_cal_168(0);                                                 //Search starting from 0xF0
  OSCCAL += 1;                                                  //Check performance for OSCCAL_WV +/- 1
  sei();
  error_up = compute_error_UNO(0,2,0);                          //Check that OSCCAL_WV is not at a
  OSCCAL -=2; error_down = compute_error_UNO(0,2,0);            //discontinuity on the
  
  OSCCAL += 1;                                                  //Restore OSCCAL to OSCCAL_WV
  if ((error_up > 500) || (error_down > 500))                     //500
  {sendString
  ("\r\nPoor result: Searching for alternative value\r\n");
  Auto_cal_168(1);} 
save_cal_values(OSCCAL_WV); 

sendString("\r\nDefault OSCCAL value ");
Num_to_PC(10,OSCCAL_DV);
sendString("\r\nNew OSCCAL value ");
Num_to_PC(10,OSCCAL_WV);

newline();
sei();
error_percent = compute_error_UNO(0,2,1)*100/32768;
if(!(error_percent)){sendString("\r\nError less than 1%\r\n");}
 else 
 { sendString("\r\nError = "); Num_to_PC(10,error_percent);
  sendString("%\r\n");}

sendString("-x- to check cal (15 Sec pause) or AOK to escape\r\n\r\n");
if (waitforkeypress() == 'x')

{Timer_T0_sub(T0_delay_20ms);
OSCCAL -= 20;
osccal_MIN = OSCCAL;                                          //Compute cal error for 41 values of OSCCAL
  for(int m = 0; m <= 40; m++)
  {cal_error = compute_error_UNO(1,2,1);OSCCAL++;}
  OSCCAL = OSCCAL_WV;                                           //Restore working value of OSCCAL
  
 for(int m = 0; m <= 40; m++)                                    //Print table of values
  {Num_to_PC(10,osccal_MIN); osccal_MIN++;
    sendChar('\t');Num_to_PC(10,buffer[m]);
    sendChar('\t');
    percentage_error = buffer[m];
    Num_to_PC(10,percentage_error*100/32768);sendChar('%');
    newline();
    Timer_T0_sub(T0_delay_20ms);
    Timer_T0_sub(T0_delay_20ms);
  Timer_T0_sub(T0_delay_20ms);}}

  
eeprom_write_byte((uint8_t*)(0x1FC),0xFF);}



/*************Program Entry point when Atmega 168 is fitted to PCB111000_V2************************************/

if (watchdog_reset == 1)watchdog_reset = 0;             //Set to 1 after mini-OS device has been calibrated
else



/********************************Read Atmega 328 (mini-OS device) calibration**************************************/

{if ((eeprom_read_byte((uint8_t*)0x1FC) == 1)\
&& (MCUSR & (1 << PORF)));                              //POR after programing target device
else  {wdt_enable(WDTO_60MS); while(1);}

while(1){                                               //User prompt is R
do{sendString("R   ");} 
while((isCharavailable(100) == 0));                     //Keypress R to complete target calibration
if(receiveChar() == 'R')break;}

eeprom_write_byte((uint8_t*)0x1FC, 0xFF);                 //Clear EEPROM location set by programmer
MCUSR &= (~(1 << PORF));

waiting_for_I2C_master;                                   //Receive cal data over I2C bus             
OSCCAL_WV = receive_byte_with_Ack();          
cal_error = receive_byte_with_Ack();          
cal_error = (cal_error << 8) + receive_byte_with_Nack();
clear_I2C_interrupt;

Text_target_cal; sendString("  ");
Num_to_PC(10, OSCCAL_WV);
sendChar('\t');
sendString("error "); 
 
 cal_error = cal_error/625;
 if(!(cal_error))sendString("less than 1%\r\n\r\n");
 else {Num_to_PC(10, cal_error);sendString("%\r\n\r\n");}
 
 
 wdt_enable(WDTO_60MS); while(1);}                        //SW reset and jump straight to user prompt P       



/************************Program entry point to program mini-OS or reinstate Atmega168 eeprom*************/

while(1){
do{sendString("P/S   ");} 
while((isCharavailable(255) == 0));  

switch(receiveChar()){

case 'S': case 's': Prog_on_chip_EEPROM();                  //Program on-chip EEPROM
wdt_enable(WDTO_60MS); while(1);break;

case 'v': case 'V': sendString (Version);
newline(); wdt_enable(WDTO_60MS); while(1);break;

case 'P': case 'p': fuse_H = 0xD0;  op_code =1; break;       //Program reset vector to 0x7000            
case 'X': case 'x': fuse_H = 0xD7; op_code =1; break;        //Program reset vector to zero                        

default:break;}if(op_code)break;}                           //Only exit loop the program target 
    
boot_target;
Atmel_powerup_and_target_detect;        
Text_Atmega;

switch (target){
case 168: sendString ("168: Not supported"); wdt_enable(WDTO_1S); break;  
case 328: sendString ("328"); PageSZ = 0x40; PAmask = 0x3FC0; 
FlashSZ=0x4000;break;      
default: wdt_enable(WDTO_1S); while(1);break;}  

Text_detected;
Text_Press_P_or_E;

while(1){

do{sendString("p/e    ");} 
while((isCharavailable(255) == 0));
op_code = receiveChar();
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

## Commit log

2024-03-08 Update I2C_V29_0_CA_header file.h
2024-03-11 Update I2C_V27_0_CA_header file.h
2024-03-15 Create I2C_V27_0_CA_header file.h
2024-03-28 Create System test.ods
    [System test.ods]
2024-03-28 Update System test.ods
    [System test.ods]
2025-11-21 Create PCB-111000_V3_Fusion_parts_list
2025-11-22 Update PCB-111000_V3_Fusion_parts_list
